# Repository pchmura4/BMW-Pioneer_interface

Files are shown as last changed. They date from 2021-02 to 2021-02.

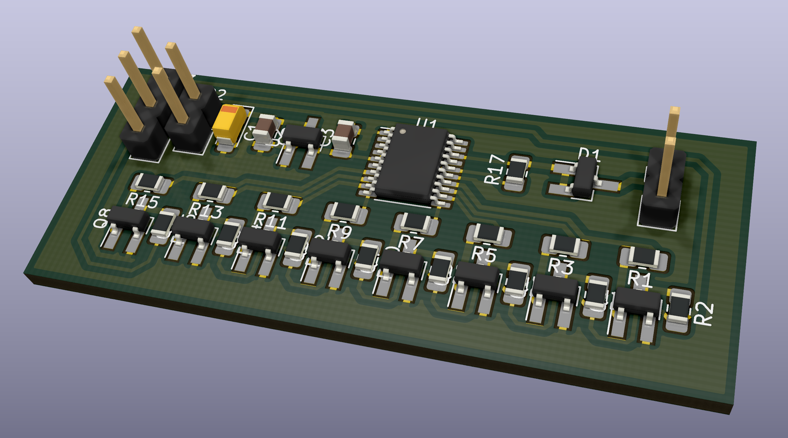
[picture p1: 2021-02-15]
HARDWARE/Board.png

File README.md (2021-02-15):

# BMW Pioneer Interface

Interface between BMW E46 steering wheel to control Pioneer aftermarket headunits  
Tested with BMW E46 AT71 and Pioneer MVH-X380BT headunit.  
In theory it should work with  
- 3 series E46 1999-2005
- 5 series E39 1996-2004
- 7 series E38 < 2001
- Z4 E85 2002-2008
- Mini 2001-2006

This circuit / software is more than 5 years old so some details can be wrong. First the input would be taken probably from PIN 7 in the big OEM radio connector. The outputs OUT and RING goes to 3.5mm jack plugged on the backside of the headunit. Voltage would best be taken from the switched power pin.  
The circuit can be done better, it was just a proof of concept. Better power supply, programming interface or the outputs optimization would make it a solid interface. It worked for about 2 years without any issues.

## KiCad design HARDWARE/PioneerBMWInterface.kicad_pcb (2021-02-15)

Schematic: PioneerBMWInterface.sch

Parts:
C1: 10uF; CP_EIA-3216-18_Kemet-A_Pad1.58x1.35mm_HandSolder
C2, C3: 100nF; C_0805_2012Metric_Pad1.18x1.45mm_HandSolder
D1: D_Schottky_x2_KCom_AAK; SOT-23_Handsoldering
P1, P2: CONN_01X02; PinHeader_1x02_P2.54mm_Vertical
P3: CONN_01X03; PinHeader_1x03_P2.54mm_Vertical
Q1, Q2, Q3, Q4, Q5, Q6, Q7, Q8: BC817-40; SOT-23_Handsoldering
R1, R17: 10k; R_0805_2012Metric_Pad1.20x1.40mm_HandSolder
R2: 1k2; R_0805_2012Metric_Pad1.20x1.40mm_HandSolder
R3: 22k; R_0805_2012Metric_Pad1.20x1.40mm_HandSolder
R4: 3k5; R_0805_2012Metric_Pad1.20x1.40mm_HandSolder
R5: 47k; R_0805_2012Metric_Pad1.20x1.40mm_HandSolder
R6: 5.8k; R_0805_2012Metric_Pad1.20x1.40mm_HandSolder
R7, R9: 100k; R_0805_2012Metric_Pad1.20x1.40mm_HandSolder
R8: 8k; R_0805_2012Metric_Pad1.20x1.40mm_HandSolder
R10: 12k; R_0805_2012Metric_Pad1.20x1.40mm_HandSolder
R11, R13: 220k; R_0805_2012Metric_Pad1.20x1.40mm_HandSolder
R12: 16k; R_0805_2012Metric_Pad1.20x1.40mm_HandSolder
R14: 24k; R_0805_2012Metric_Pad1.20x1.40mm_HandSolder
R15: 2k2; R_0805_2012Metric_Pad1.20x1.40mm_HandSolder
R16: 100R; R_0805_2012Metric_Pad1.20x1.40mm_HandSolder
U1: STM32F030F4P6; TSSOP-20_4.4x6.5mm_P0.65mm
U2: MCP1792T-3302H; SOT-23_Handsoldering

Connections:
1k2: R1.1, U1.14 (PB1)
3k5: R3.1, U1.13 (PA7)
5k8: R5.1, U1.12 (PA6)
8k: R7.1, U1.11 (PA5)
12k: R9.1, U1.10 (PA4)
16k: R11.1, U1.9 (PA3)
24k: R13.1, U1.8 (PA2)
GND: C1.2, C2.2, C3.2, P1.2, P2.2, P3.3, Q1.2 (E), Q2.2 (E), Q3.2 (E), Q4.2 (E), Q5.2 (E), Q6.2 (E), Q7.2 (E), Q8.2 (E), U1.1 (BOOT0), U1.15 (VSS), U2.1 (GND)
unnamed: C1.1, C2.1, P2.1, U2.3 (VIN)
unnamed: D1.1 (A), D1.2 (A), R17.2, U1.18 (PA10)
unnamed: D1.3 (K), P1.1
unnamed: Q1.1 (B), R1.2
unnamed: Q1.3 (C), R2.1
unnamed: Q2.1 (B), R3.2
unnamed: Q2.3 (C), R4.1
unnamed: Q3.1 (B), R5.2
unnamed: Q3.3 (C), R6.1
unnamed: Q4.1 (B), R7.2
unnamed: Q4.3 (C), R8.1
unnamed: Q5.1 (B), R9.2
unnamed: Q5.3 (C), R10.1
unnamed: Q6.1 (B), R11.2
unnamed: Q6.3 (C), R12.1
unnamed: Q7.1 (B), R13.2
unnamed: Q7.3 (C), R14.1
unnamed: Q8.1 (B), R15.2
unnamed: Q8.3 (C), R16.1
OUT: P3.1, R2.2, R4.2, R6.2, R8.2, R10.2, R12.2, R14.2
RING: R15.1, U1.7 (PA1)
RING_OUT: P3.2, R16.2
VCC: C3.1, R17.1, U1.4 (NRST), U1.5 (VDDA), U1.16 (VDD), U2.2 (VOUT)

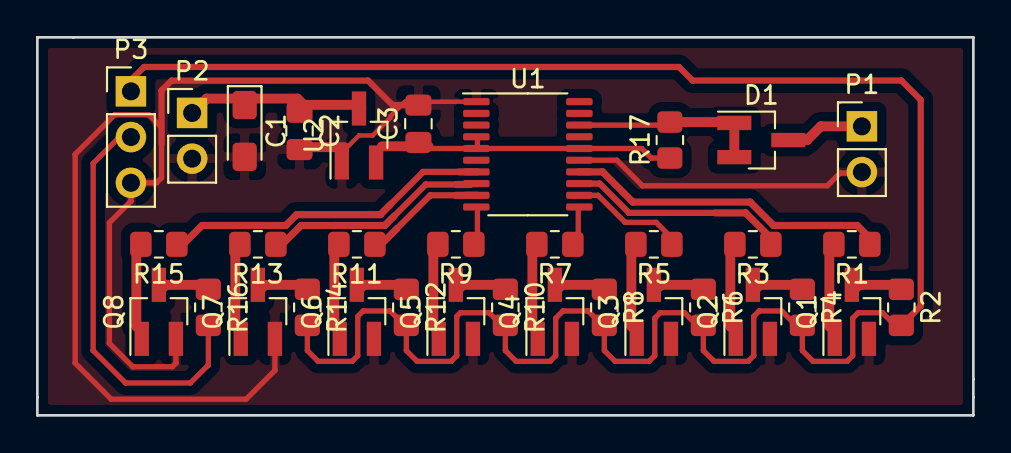
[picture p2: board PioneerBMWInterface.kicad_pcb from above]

Board: 2 copper layers, 52.0 x 21.0 mm, 34 parts (0 on the bottom side), 31 nets.

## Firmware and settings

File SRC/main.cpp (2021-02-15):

/**
  ******************************************************************************
  * @file    main.c 
  * @author  Patryk Chmura
  * @version V1.0.0
  * @date    08-December-2015
  * @brief   Pioneer radio interface to BMW OEM steering wheel controls
  ******************************************************************************
  */

/* Includes ------------------------------------------------------------------*/
#include "main.h"

/* Private typedef -----------------------------------------------------------*/
/* Private define ------------------------------------------------------------*/
/* Private macro -------------------------------------------------------------*/
/* Private variables ---------------------------------------------------------*/
volatile static uint32_t uwTick;
volatile uint16_t mode_count=0, source_count=12000;
volatile bool source_deactivate=false, mode_hold=false;
volatile uint8_t rxBuffer[rxBuffSize];


/* Private function prototypes -----------------------------------------------*/
/* Private functions ---------------------------------------------------------*/

/**
  * @brief  Main program.
  * @param  None
  * @retval None
  */
int main(void)
{
	Button2F_t DialButton = Btn2F_NOTHING;
	Ignition_t Ignition = Ign_NOTHING;
	uint32_t rxIndex = 0;
	PioneerInterface Radio;
	BMWbus SWheel;
	
	HardwareInit();
	
	if(ResetByIWDG())		source_count = 0;
	else								source_count = 12000;

	// Infinite loop
	for(;;)
	{
		IWDGRefresh();
		
		uint32_t rxWaiting = rxBuffSize - DMA1_Channel3->CNDTR;
		uint32_t bufCnt = rxWaiting - (rxIndex % rxBuffSize);
		bufCnt = bufCnt % rxBuffSize;
		while(bufCnt)
		{
			uint8_t rxByte = rxBuffer[rxIndex % rxBuffSize]; rxIndex++; bufCnt--;
			SWheel.parse(rxByte);
		}
		
		if((SWheel.isAvailable()))
		{
			switch(SWheel.interpret())
			{
				case Next_release:
					if(!mode_count)
					{
						Radio.TuneRt_release();
					}
					break;
					
				case Prev_release:
					if(!mode_count)
					{
						Radio.TuneLt_release();
					}	
					break;
					
				case VolUp_press:
					if(!mode_count)
					{
 						Radio.VolUp_push();
					}
					else
					{
						Radio.BTAnswer();
						Delay(TIME2);
						mode_count = 10;
					}
					break;
					
				case VolDn_press:
					if(!mode_count)
					{
						Radio.VolDn_push();
					}
					else
					{
						Radio.BTReject();
						Delay(TIME2);
						mode_count = 10;
					}
					break;
					
				case Next_press:
					if(!mode_count)
					{
						Radio.TuneRt_press();
					}
					else
					{
						Radio.FolderUp();
						Delay(TIME2);
						mode_count = 10;
					}
					break;
					
				case Prev_press:
					if(!mode_count)
					{
						Radio.TuneLt_press();
					}
					else
					{
						Radio.FolderDn();
						Delay(TIME2);
						mode_count = 10;
					}
					break;
					
				case RT_pushed:
					if(source_deactivate == false)
					{
						if(!mode_count)
						{
							Radio.Source();
						}
						else
						{
							Radio.Mute();
							Delay(TIME2);
							mode_count = 10;
						}
					}
					break;
					
				case Dial_press:
					DialButton = Pressed;
					break;
				
				case Dial_1s:
					DialButton = Pressed1s;
					break;
					
				case Dial_release:
					if(DialButton == Pressed)					mode_hold = false;
					else if(DialButton == Pressed1s)	mode_hold = true;
					DialButton = Btn2F_NOTHING;
					mode_count = (mode_count>0) ? 0 : 3000;	// set alternative mode for 5 seconds, if it's set already - clear it
					break;
				
				case Pos1_Acc:
					Ignition = Pos1Acc;
					source_count = 12000;
					break;
					
				case Pos3_Start:
					Ignition  = Pos3Start;
					break;
					
				case Pos2_On:
					if(Ignition == Pos1Acc)					__NOP();
					else if(Ignition == Pos3Start)	source_count = 12000;
					Ignition = Ign_NOTHING;
					break;
				
				default:
					break;
			}
		}
	}
}


void Delay(uint32_t delay)
{
	uint32_t tickstart = 0;
	tickstart = uwTick;
	while((uwTick - tickstart) < delay);
}


/******************************************************************************/
/*            Cortex-M0 Processor Exceptions Handlers                         */
/******************************************************************************/
extern "C" {
/**
  * @brief  This function handles NMI exception.
  * @param  None
  * @retval None
  */
void NMI_Handler(void)
{
}

/**
  * @brief  This function handles Hard Fault exception.
  * @param  None
  * @retval None
  */
void HardFault_Handler(void)
{
	/* Go to infinite loop when Hard Fault exception occurs */
	while (1)
	{
	}
}

/**
  * @brief  This function handles SVCall exception.
  * @param  None
  * @retval None
  */
void SVC_Handler(void)
{
}

/**
  * @brief  This function handles PendSVC exception.
  * @param  None
  * @retval None
  */
void PendSV_Handler(void)
{
}

/**
  * @brief  This function handles SysTick Handler.
  * @param  None
  * @retval None
  */

void SysTick_Handler(void)
{
	uwTick++;
	
	if((mode_count > 0) && (mode_hold == false))	mode_count--;
	
	if(source_count > 0)
	{
		source_count--;		// BMW module sends source command 3 times in exact time windows everytime ignition is turned on, ignoring so it's not triggered
		if((source_count < 11000) && (source_count > 10000))		source_deactivate = true;
		else if((source_count < 7000) && (source_count > 6000))	source_deactivate = true;
		else if((source_count < 2000) && (source_count > 1000)) source_deactivate = true;
		else	source_deactivate = false;
	}
}
} // extern "C"

/**
  * @}
  */

/************************ (C) COPYRIGHT STMicroelectronics *****END OF FILE****/

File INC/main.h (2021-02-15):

#ifndef __MAIN_H__
#define __MAIN_H__


#include "stm32f0xx.h"
#include "hardware.h"
#include "PioneerInterface.h"
#include "BMWbus.h"


#define IWDG_REFRESH      (uint32_t)(0x0000AAAA)
#define IWDG_WRITE_ACCESS (uint32_t)(0x00005555)
#define IWDG_START        (uint32_t)(0x0000CCCC)
#define IWDG_RELOAD       (469)				// max 2047, RLR has 11-bits -> (1/(40000/256))*469 = 3s


#define rxBuffSize	64


#define TIME	80
#define TIME2	500


#define RING_ON() 	GPIOA->BSRR = GPIO_ODR_1	// PA1
#define RING_OFF()	GPIOA->BRR  = GPIO_ODR_1	// PA1

#define R24k	GPIO_ODR_2	// PA2
#define R16k	GPIO_ODR_3	// PA3
#define R12k	GPIO_ODR_7	// PA7
#define R8k		GPIO_ODR_5	// PA5
#define R5k5	GPIO_ODR_6	// PA6				16k || 8k = 5.33k
#define R1k2	GPIO_ODR_1	// PB1

#define R24k_ON()		GPIOA->BSRR = R24k
#define R24k_OFF()	GPIOA->BRR  = R24k
#define R16k_ON()		GPIOA->BSRR = R16k
#define R16k_OFF()	GPIOA->BRR  = R16k
#define R12k_ON()		GPIOA->BSRR = R12k
#define R12k_OFF()	GPIOA->BRR  = R12k
#define R8k_ON()		GPIOA->BSRR = R8k
#define R8k_OFF()		GPIOA->BRR  = R8k
#define R5k5_ON()		GPIOA->BSRR = R5k5
#define R5k5_OFF()	GPIOA->BRR  = R5k5
#define R1k2_ON()		GPIOB->BSRR = R1k2
#define R1k2_OFF()	GPIOB->BRR  = R1k2


enum Button2F_t
{
	Btn2F_NOTHING,
	Pressed,
	Pressed1s
};

enum Ignition_t
{
	Ign_NOTHING,
	Pos1Acc,
	Pos3Start
};


void Delay(uint32_t);

extern volatile uint8_t rxBuffer[rxBuffSize];


#endif

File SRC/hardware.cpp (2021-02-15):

#include "hardware.h"


void HardwareInit(void)
{
	SysTick_Config(SystemCoreClock/1000);	// 1ms config
	Configure_IWDG();
	Configure_GPIO_OUT();
	Configure_GPIO_USART1();
	Configure_DMA1();
	Configure_USART1();
}


void IWDGRefresh(void)
{
	IWDG->KR = IWDG_REFRESH;
}


bool ResetByIWDG(void)
{
	// check if IWDG caused CPU reset
	if((RCC->CSR & RCC_CSR_IWDGRSTF) == RCC_CSR_IWDGRSTF)
	{
		RCC->CSR |= RCC_CSR_RMVF;		// clear reset flag
		return true;
	}
	else
	{
		return false;
	}
}


void Configure_IWDG(void)
{
	RCC->CSR |= RCC_CSR_LSION;

	int timeout=0xFFF;
	while((RCC->CSR & RCC_CSR_LSIRDY) != RCC_CSR_LSIRDY) // wait until it's ready
	{
		if(!(timeout--))
			break;
	}

	IWDG->KR = IWDG_START;				// activate IWDG (not needed if done in option bytes)
	IWDG->KR = IWDG_WRITE_ACCESS;	// enable write access to IWDG registers
	IWDG->PR = IWDG_PR_PR_1 | IWDG_PR_PR_2;	// set prescaler by 256		(40khz/256 = 156,25Hz = 6,4ms)
	IWDG->RLR = IWDG_RELOAD;			// set reload value to have a rollover each 100ms

	timeout=0xFFF;
	while(IWDG->SR)
	{ 
	if(!(timeout--))
			break;
	}

	IWDGRefresh();
}


void Configure_GPIO_OUT(void)
{
	RCC->AHBENR |= RCC_AHBENR_GPIOAEN;
	RCC->AHBENR |= RCC_AHBENR_GPIOBEN;

	GPIOB->MODER = (GPIOB->MODER & ~(GPIO_MODER_MODER1)) | (GPIO_MODER_MODER1_0);

	GPIOA->MODER = (GPIOA->MODER & ~(GPIO_MODER_MODER1 | GPIO_MODER_MODER2)) | (GPIO_MODER_MODER1_0 | GPIO_MODER_MODER2_0);
	GPIOA->MODER = (GPIOA->MODER & ~(GPIO_MODER_MODER3 | GPIO_MODER_MODER4)) | (GPIO_MODER_MODER3_0 | GPIO_MODER_MODER4_0);	
	GPIOA->MODER = (GPIOA->MODER & ~(GPIO_MODER_MODER5 | GPIO_MODER_MODER6)) | (GPIO_MODER_MODER5_0 | GPIO_MODER_MODER6_0);
	GPIOA->MODER = (GPIOA->MODER & ~(GPIO_MODER_MODER7 | GPIO_MODER_MODER8)) | (GPIO_MODER_MODER7_0 | GPIO_MODER_MODER8_0);
}


void Configure_GPIO_USART1(void)
{
	RCC->AHBENR |= RCC_AHBENR_GPIOAEN;

	GPIOA->MODER = (GPIOA->MODER & ~(GPIO_MODER_MODER10)) | (GPIO_MODER_MODER10_1);
	GPIOA->AFR[1] = (GPIOA->AFR[1] &~ (GPIO_AFRH_AFRH2))  | (1 << (2 * 4));
}


void Configure_DMA1(void)
{
	RCC->AHBENR |= RCC_AHBENR_DMA1EN;

	DMA1_Channel3->CPAR = (uint32_t)&(USART1->RDR);
	DMA1_Channel3->CMAR = (uint32_t)rxBuffer;
	DMA1_Channel3->CNDTR = rxBuffSize;
	DMA1_Channel3->CCR  = DMA_CCR_CIRC | DMA_CCR_MINC | DMA_CCR_EN;
}


void Configure_USART1(void)
{
	RCC->APB2ENR |= RCC_APB2ENR_USART1EN;

	USART1->BRR = SystemCoreClock / 9600;
	USART1->CR3 = USART_CR3_DMAR;
	USART1->CR1 = USART_CR1_M0 | USART_CR1_PCE | USART_CR1_RE | USART_CR1_UE;

	int timeout=0xFFF;
	while((USART1->ISR & USART_ISR_TC) != USART_ISR_TC) // polling idle frame Transmission
	{
		if(!(timeout--))
			break;
	}
	USART1->ICR |= USART_ICR_TCCF;	// clear TC flag
	USART1->CR1 |= USART_CR1_TCIE;	// enable TC interrupt
}
